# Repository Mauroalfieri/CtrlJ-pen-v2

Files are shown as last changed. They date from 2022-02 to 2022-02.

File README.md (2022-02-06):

# CtrlJ-pen-v2
The CtrlJ pen is a tool that can automatically control a syringe and fluid such as solder-past, for smd components, or silicone.
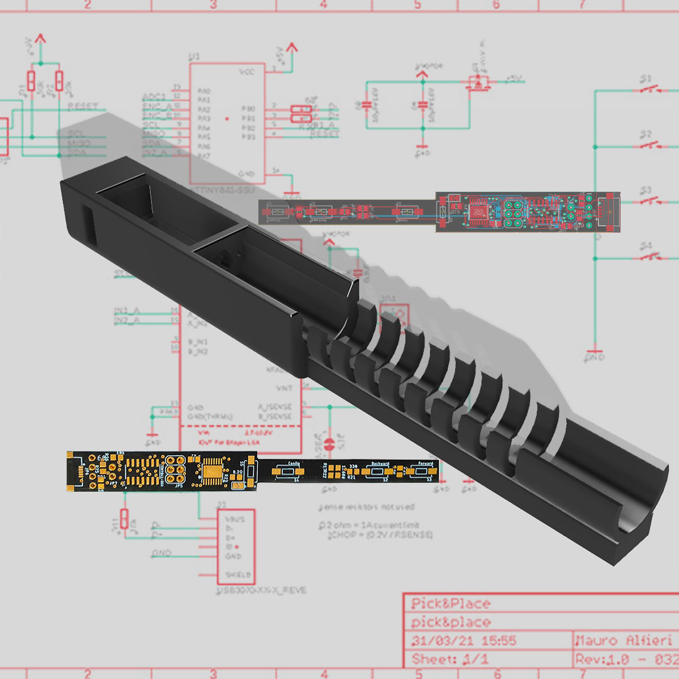
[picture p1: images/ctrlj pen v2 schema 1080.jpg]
Render CtrlJ pen v2


More info about this project on my Blog: [mauroalfieri.it](https://mauroalfieri.it)

### 3D parts designed
CtrlJ pen v2 3D parts is made with Fusion 360:

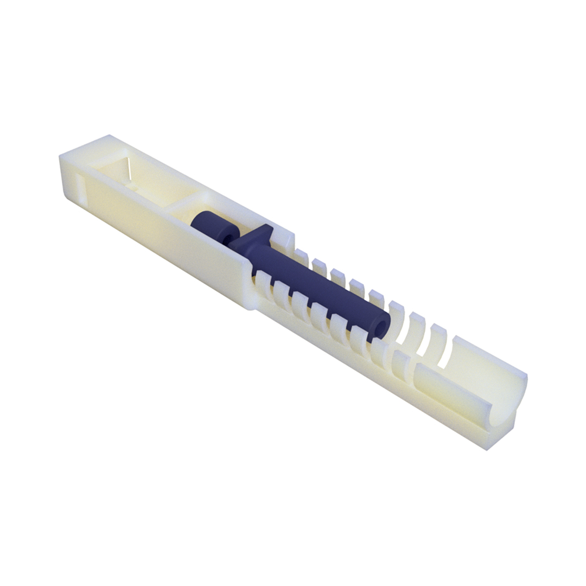
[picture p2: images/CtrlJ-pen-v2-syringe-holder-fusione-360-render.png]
Render CtrlJ pen v2


The main changes concern the motor and pcb case, that in this version are integrated into the pen itself.

The syringe holder is the main part of the project:

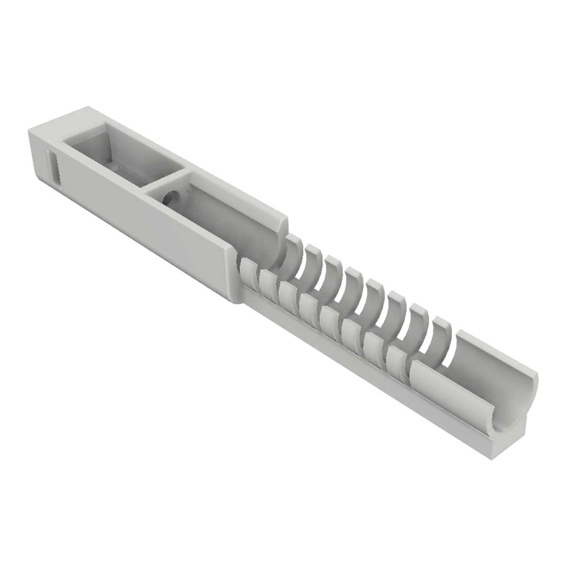
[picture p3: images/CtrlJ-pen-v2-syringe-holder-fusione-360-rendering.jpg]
Syringe holder
<p align=center>
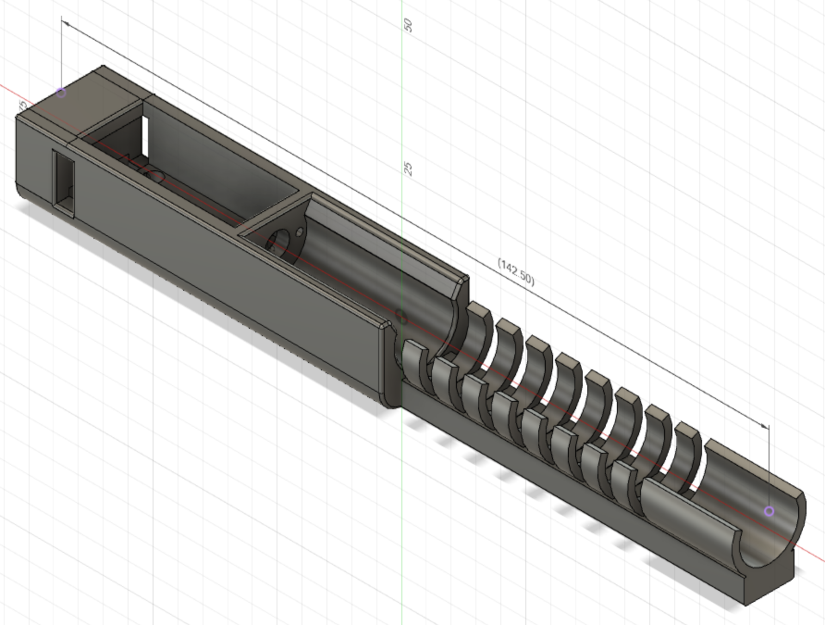
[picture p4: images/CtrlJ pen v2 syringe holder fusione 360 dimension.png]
Syringe holder sizes

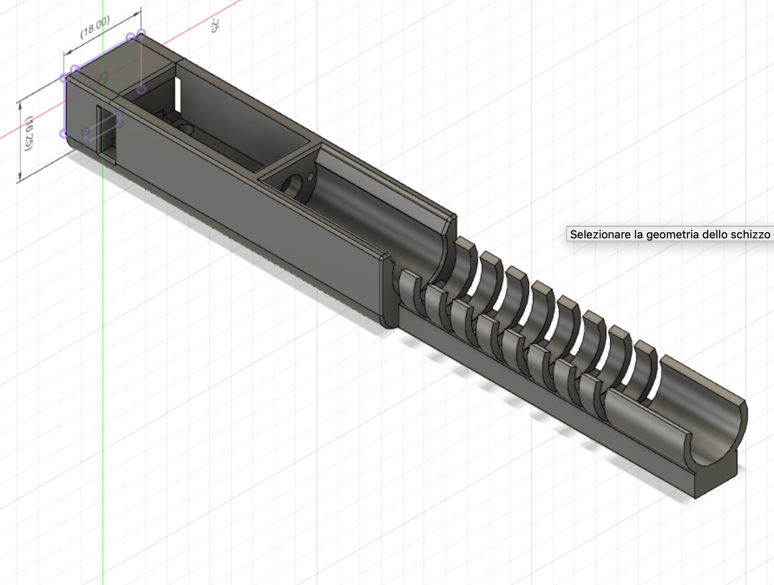
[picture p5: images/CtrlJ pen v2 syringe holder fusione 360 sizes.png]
Syringe holder sizes
</p>

with it sizes is L=142,5mm H=16,25mm P=18mm.

The other two 3D parts are the motor connector and the plunger pad to push the syringe plunger:

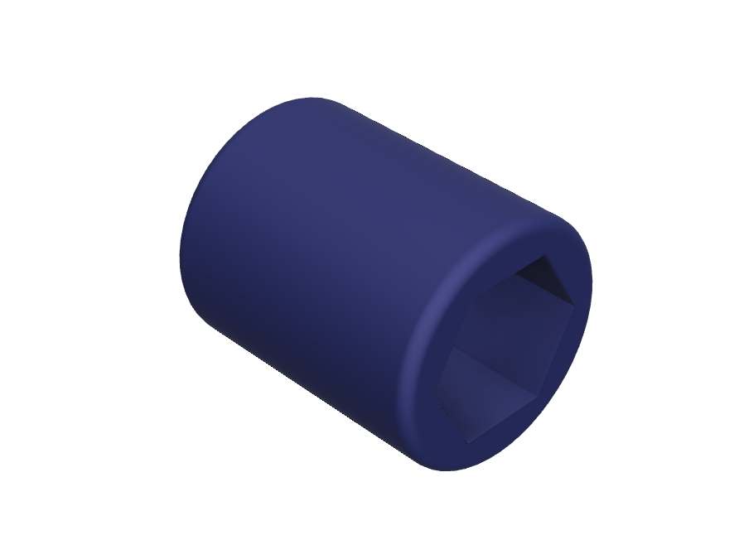
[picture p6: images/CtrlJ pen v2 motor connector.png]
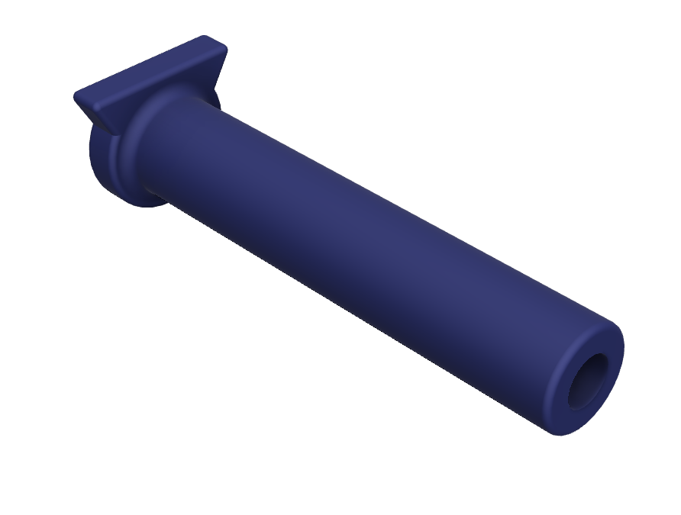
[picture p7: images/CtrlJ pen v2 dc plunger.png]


### PCB and schema
The electronic schema designed with Eagle software is tha following:

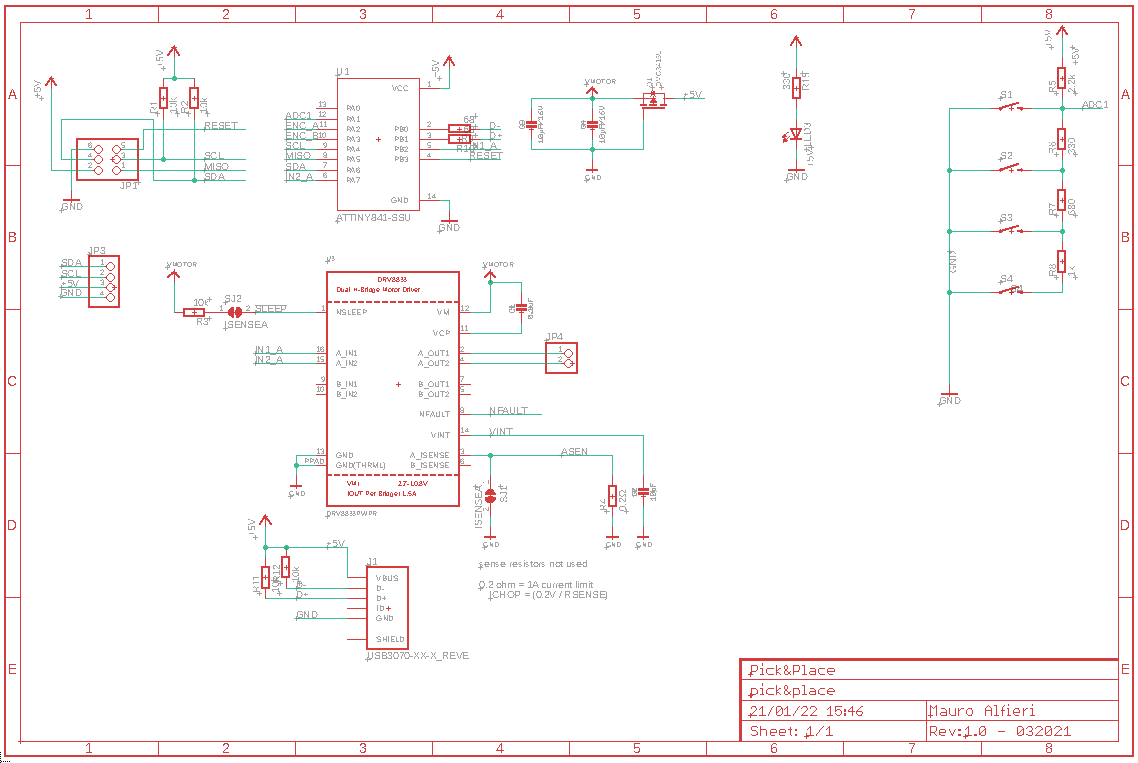
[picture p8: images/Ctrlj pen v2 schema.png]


nn Eagle, you can place electronic components in specific coordinates and generate a PCB:

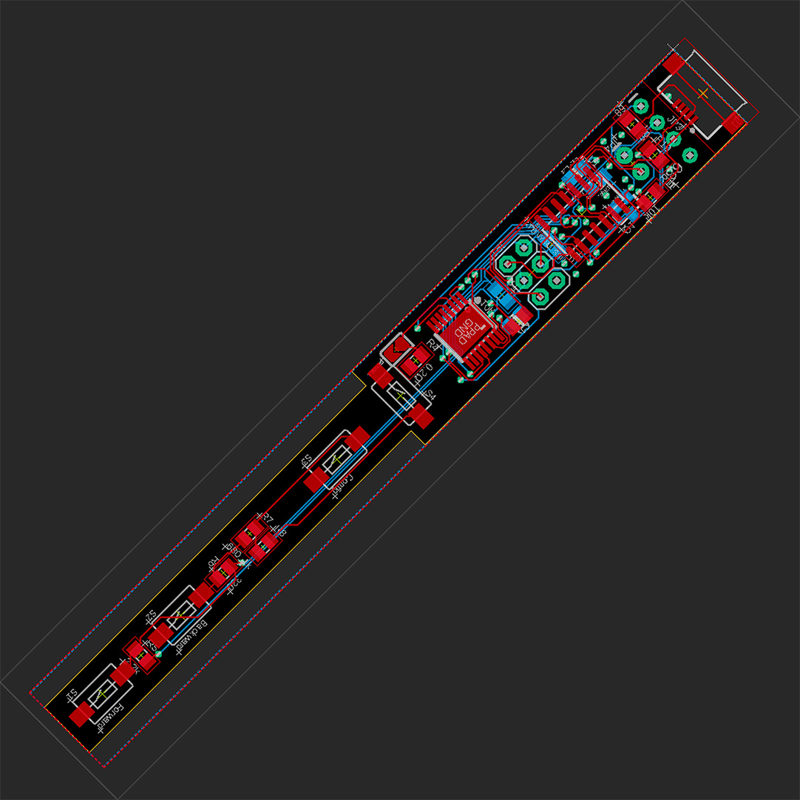
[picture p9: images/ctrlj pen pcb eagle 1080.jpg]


to be inserted in the 3D printed case.

### The printed case
The case designed with Fusion 360 has been printed using my Prusa i3 and PLA+ filament, the result is as follows:

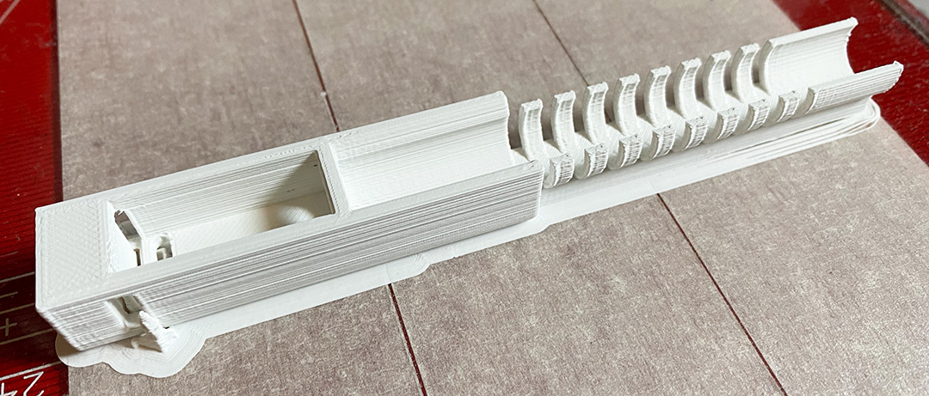
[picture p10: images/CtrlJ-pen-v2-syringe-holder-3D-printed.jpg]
Syringe holder sizes

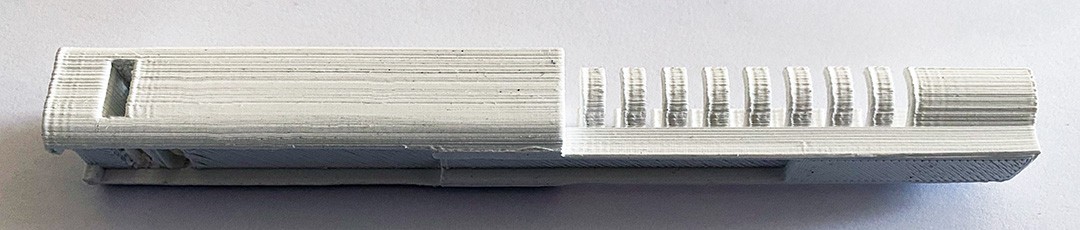
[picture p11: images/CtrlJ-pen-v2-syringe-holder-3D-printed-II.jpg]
Syringe holder sizes

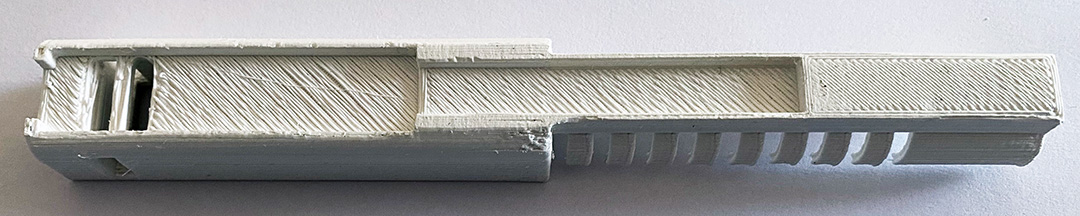
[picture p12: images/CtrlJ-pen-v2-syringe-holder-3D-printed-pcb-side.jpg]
Syringe holder sizes


and the two components:

the syringe plunger thrust system
the connector between the motor and the syringe.

were printed with a blue filament for aesthetical reasons only:

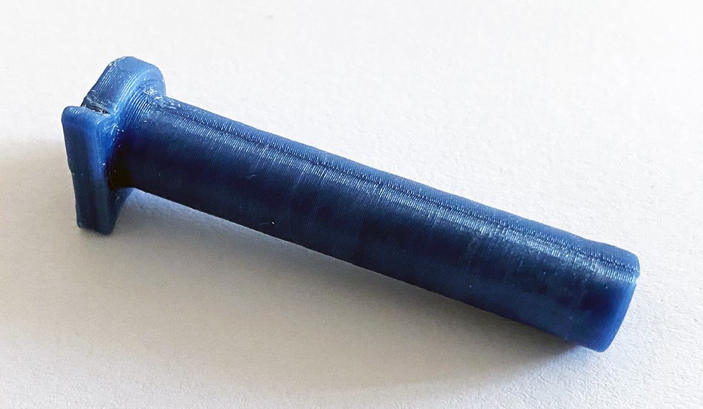
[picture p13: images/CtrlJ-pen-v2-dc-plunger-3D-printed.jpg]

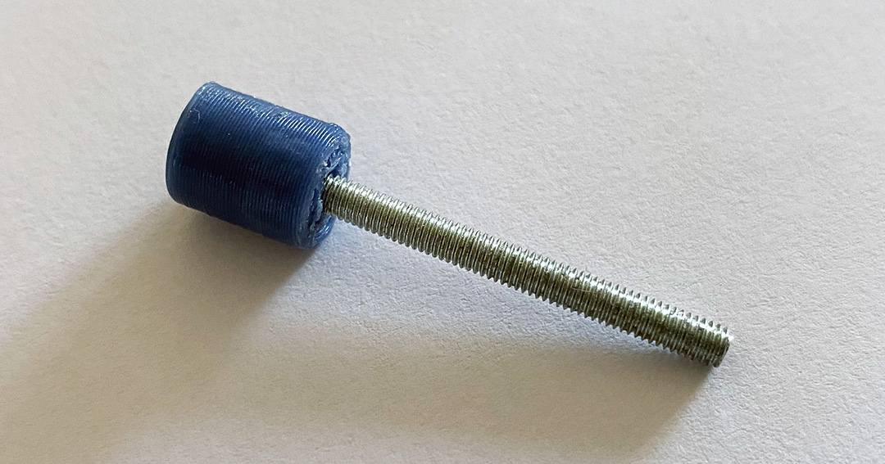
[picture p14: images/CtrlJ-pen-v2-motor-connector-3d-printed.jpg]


This project is released as is, without responsibility and is a DIY project under continuous development.

If you are interested you can leave a comment or contact me on the blog: [mauroalfieri.it](https://mauroalfieri.it)

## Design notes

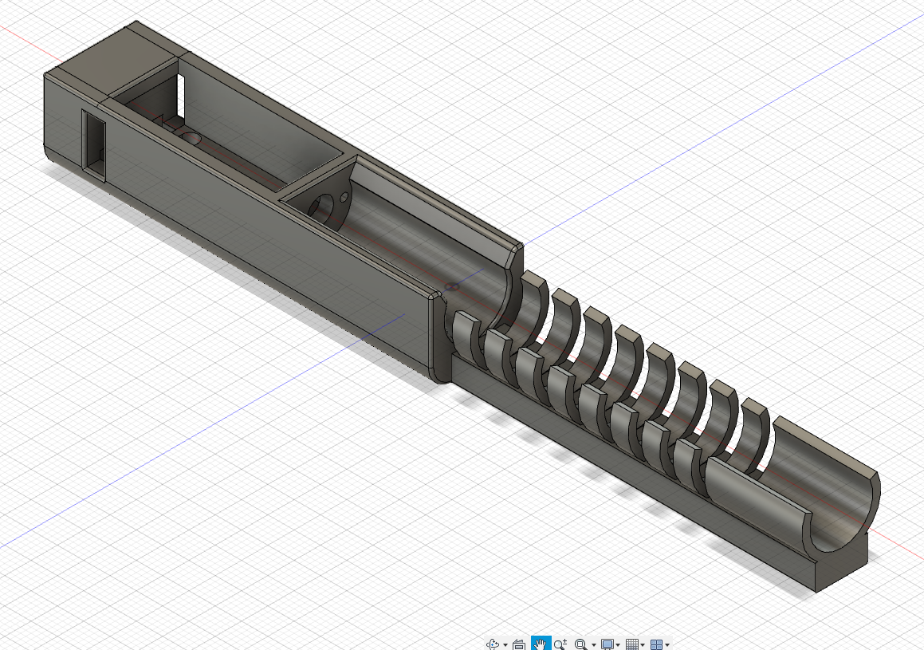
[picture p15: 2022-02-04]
images/CtrlJ pen v2 syringe holder fusione 360.png

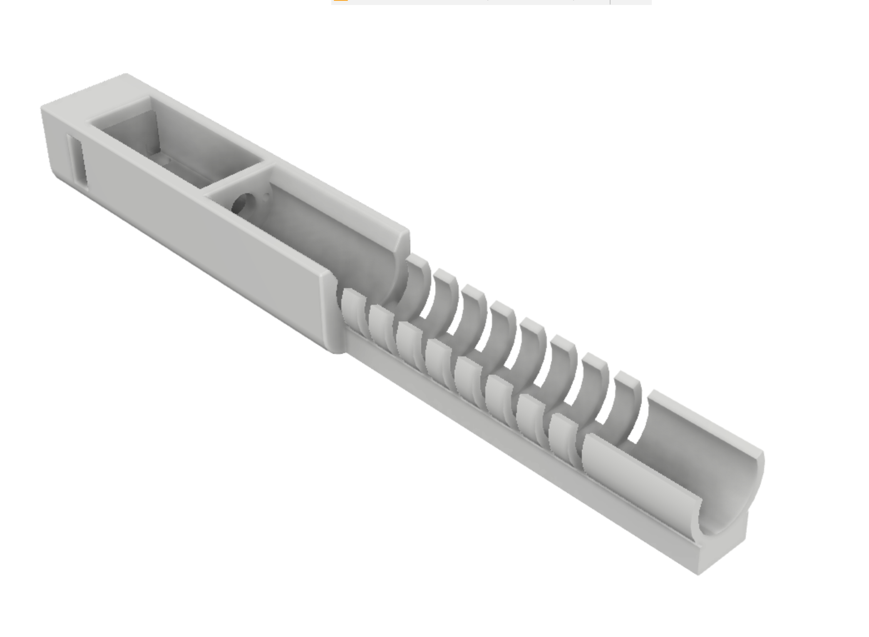
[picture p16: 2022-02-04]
images/CtrlJ pen v2 syringe holder fusione 360 rendering.png

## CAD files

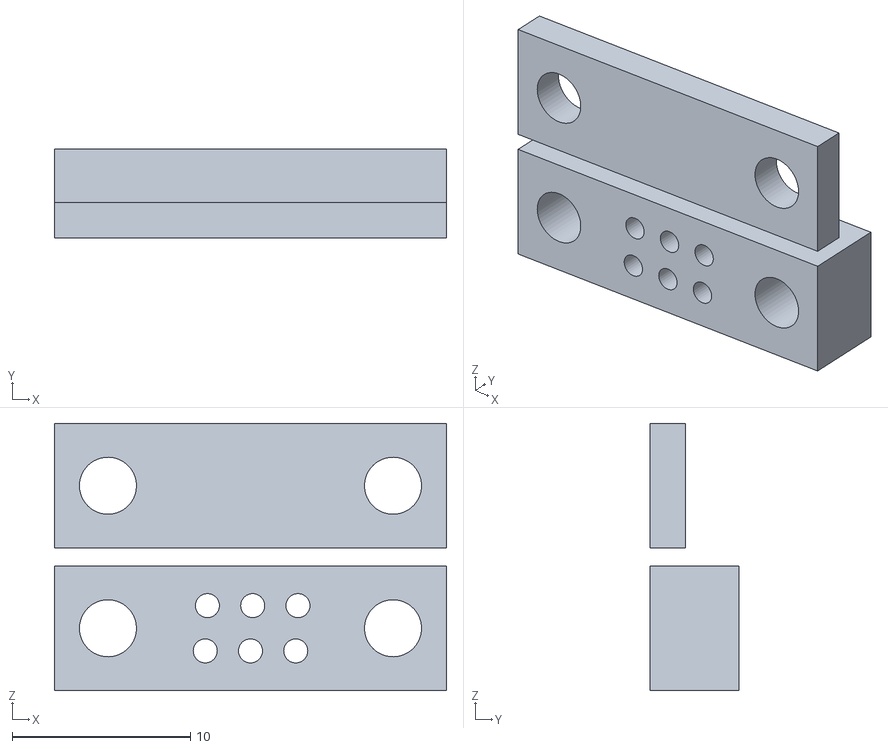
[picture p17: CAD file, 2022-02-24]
stl/programmer tool/pogopin_holder.stl
22.0 x 5.00 x 15.0

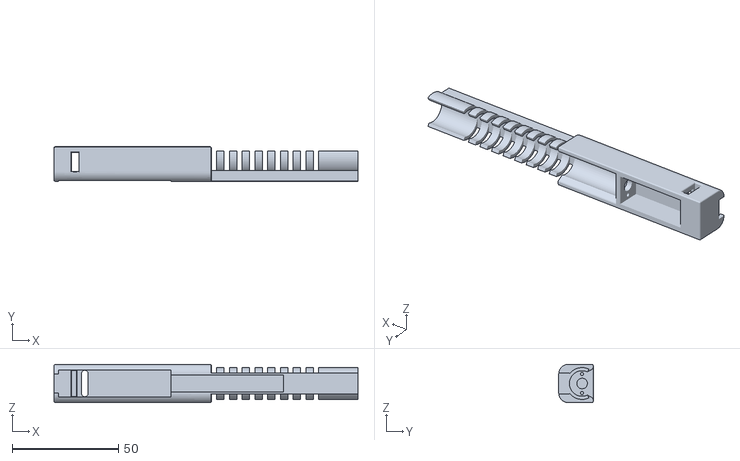
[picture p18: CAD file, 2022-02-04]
stl/syringe_holder_dc.stl
143.0 x 16.3 x 18.0

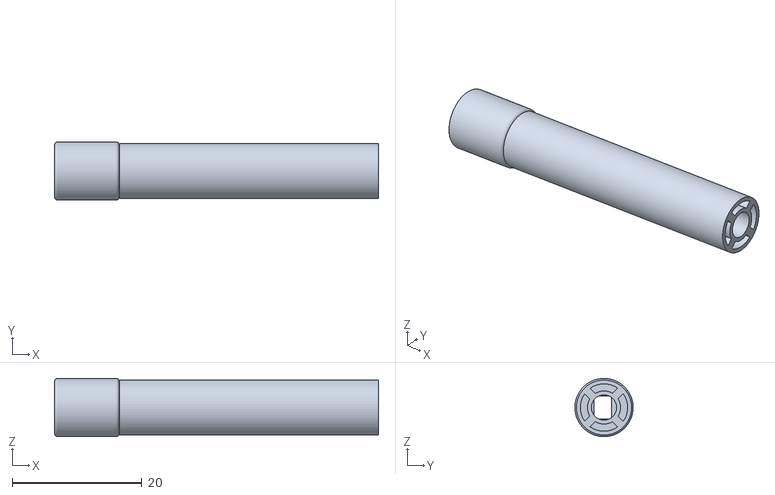
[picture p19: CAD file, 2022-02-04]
stl/motor_connector.stl
50.0 x 9.00 x 9.00

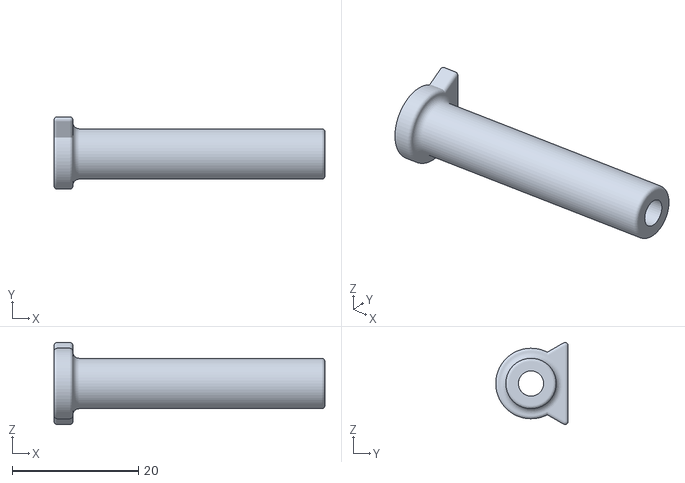
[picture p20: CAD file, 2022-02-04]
stl/dc_plunger.stl
43.0 x 11.5 x 13.0

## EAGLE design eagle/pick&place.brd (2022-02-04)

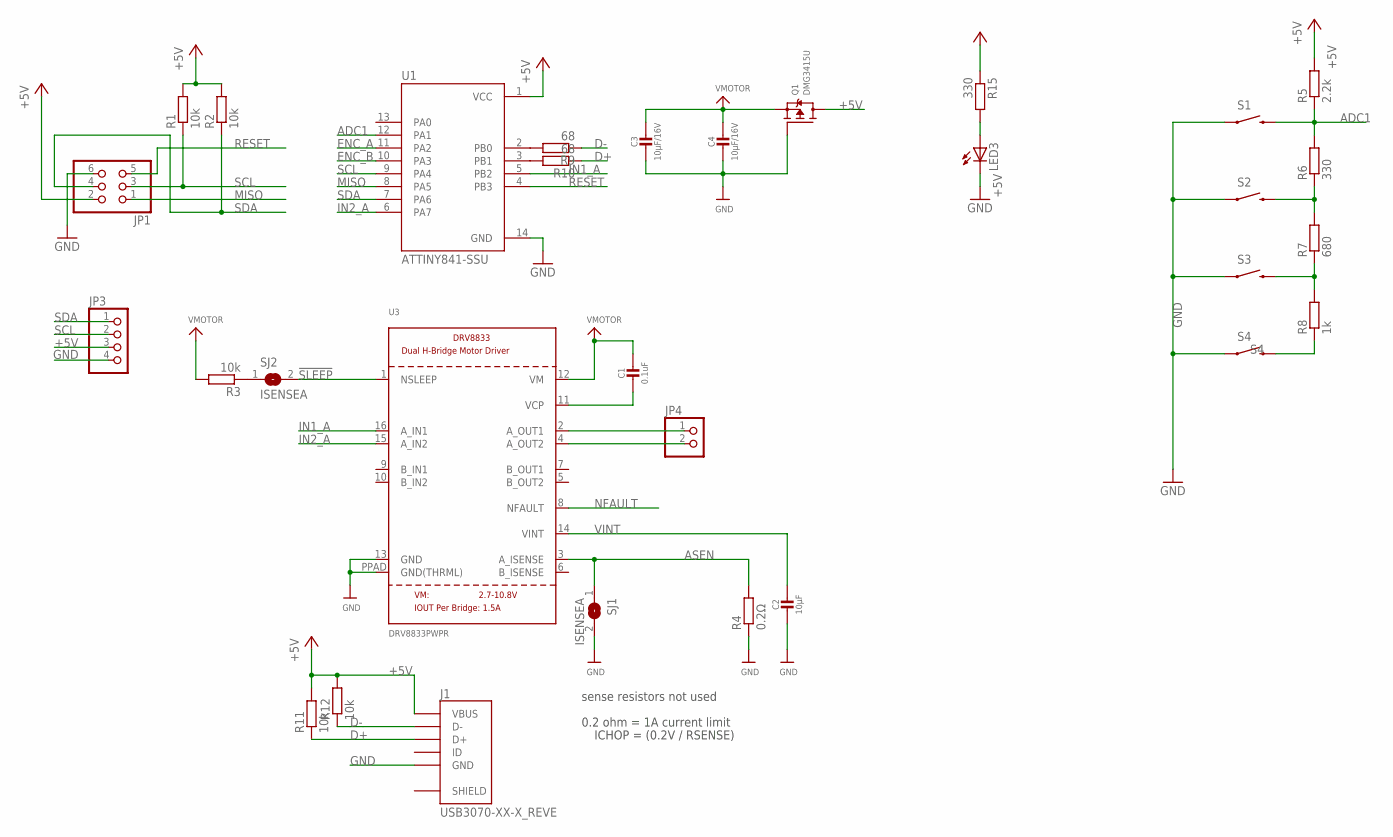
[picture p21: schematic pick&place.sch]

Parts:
C1: 0.1uF; 0805-NO
C2: 10µF; 0805-NO
C3, C4: 10µF/16V; 0805-NO
J1: USB3070-XX-X_REVE; GCT_USB3070-XX-X_REVE
JP1: PINHD-2X3; 2X03
JP3: HEADER-1X4ROUND; 1X04_ROUND
JP4: HEADER-1X2ROUND; 1X02_ROUND
LED3: LEDSML0805; SML0805
Q1: DMG3415U; SOT23-WIDE
R1, R2, R3, R11, R12: 10k; R0805
R4: 0.2Ω; R0805
R5: 2.2k; R0805
R6, R15: 330; R0805
R7: 680; R0805
R8: 1k; R0805
R9, R10: 68; R0805
S1: Forward; TACTILE-SWITCH-1101NE
S2: Backward; TACTILE-SWITCH-1101NE
S3: Config; TACTILE-SWITCH-1101NE
S4: SWITCH-MOMENTARY-2-SMD-1101NE; TACTILE-SWITCH-1101NE
SJ1, SJ2: ISENSEA; SOLDERJUMPER_ARROW_NOPASTE
U1: ATTINY841-SSU; SOIC127P599X175-14N
U3: DRV8833PWPR; HTSSOP16

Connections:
!SLEEP: SJ2.2, U3.1 (NSLEEP)
+5V: J1.1 (VBUS), JP1.2, JP3.3, Q1.3 (D), R1.2, R2.2, R5.2, R11.2, R12.2, R15.1, U1.1 (VCC)
ADC1: R5.1, R6.2, S1.P$2 (2), U1.12 (PA1)
AOUT1: JP4.1, U3.2 (A_OUT1)
AOUT2: JP4.2, U3.4 (A_OUT2)
ASEN: R4.2, SJ1.1, U3.3 (A_ISENSE)
D+: J1.3 (D+), R10.1, R11.1
D-: J1.2 (D-), R9.1, R12.1
ENC_A: U1.11 (PA2)
ENC_B: U1.10 (PA3)
GND: C2.2, C3.2, C4.2, J1.5 (GND), JP1.6, JP3.4, LED3.C, Q1.1 (G), R4.1, S1.P$1 (1), S2.P$1 (1), S3.P$1 (1), S4.P$1 (1), SJ1.2, U1.14 (GND), U3.13 (GND), U3.PPAD (GND(THRML))
IN1_A: U1.5 (PB2), U3.16 (A_IN1)
IN2_A: U1.6 (PA7), U3.15 (A_IN2)
MISO: JP1.1, U1.8 (PA5)
unnamed: R3.1, SJ2.1
unnamed: R9.2, U1.2 (PB0)
unnamed: R10.2, U1.3 (PB1)
unnamed: C1.2, U3.11 (VCP)
unnamed: R7.1, R8.2, S3.P$2 (2)
unnamed: LED3.A, R15.2
unnamed: R6.1, R7.2, S2.P$2 (2)
NFAULT: U3.8 (NFAULT)
RESET: JP1.5, U1.4 (PB3)
S4: R8.1, S4.P$2 (2)
SCL: JP1.3, JP3.2, R1.1, U1.9 (PA4)
SDA: JP1.4, JP3.1, R2.1, U1.7 (PA6)
SHIELD: J1.6 (SHIELD), J1.7 (SHIELD)
VINT: C2.1, U3.14 (VINT)
VMOTOR: C1.1, C3.1, C4.1, Q1.2 (S), R3.2, U3.12 (VM)

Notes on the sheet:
sense resistors not used
0.2 ohm = 1A current limit
ICHOP = (0.2V / RSENSE)

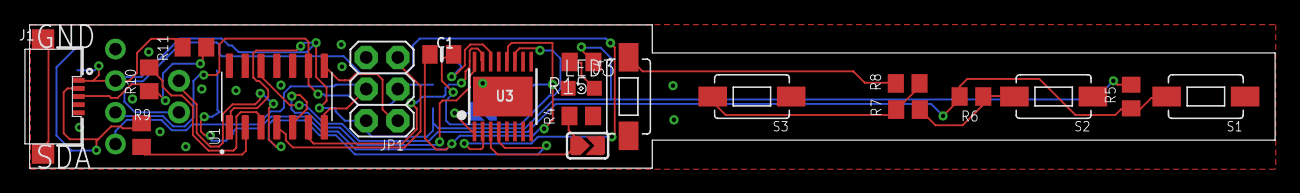
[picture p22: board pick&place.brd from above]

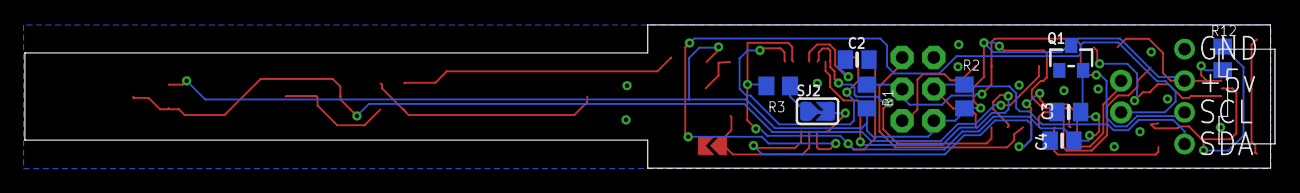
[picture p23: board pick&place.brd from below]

Board: 2 copper layers, 100.0 x 11.5 mm, 31 parts (9 on the bottom side), 26 nets.

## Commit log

2022-02-04 First Upload
    [dc_plunger.stl, motor_connector.stl, pick&place.brd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]
2022-02-05 folder src renamed in eagle
    [pick&place.brd, pick&place.sch]
2022-02-24 added stl file
    [pogopin_holder.stl]

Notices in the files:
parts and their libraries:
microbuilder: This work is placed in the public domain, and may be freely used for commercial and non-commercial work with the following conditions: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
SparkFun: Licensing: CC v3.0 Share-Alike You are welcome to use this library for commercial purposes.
